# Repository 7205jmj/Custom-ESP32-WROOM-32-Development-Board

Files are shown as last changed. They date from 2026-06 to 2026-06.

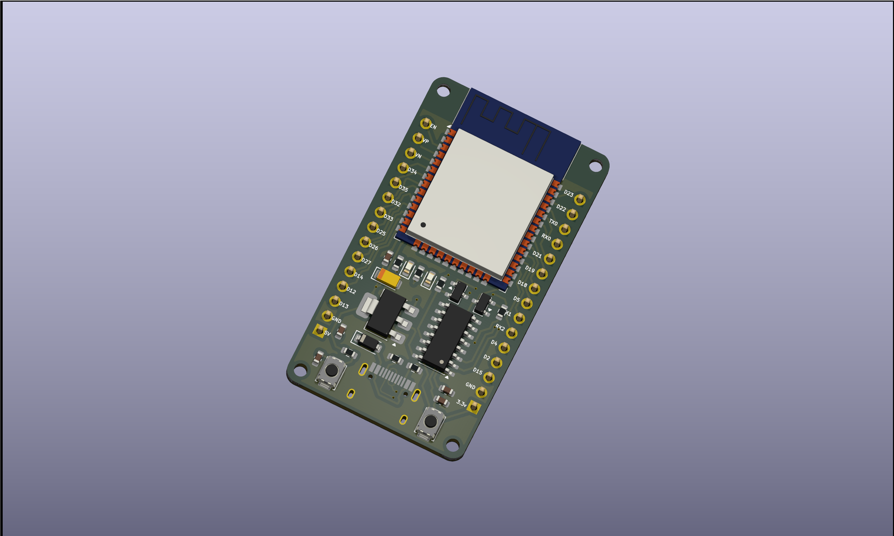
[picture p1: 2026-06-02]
3d_model.png

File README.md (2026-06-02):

# Custom-ESP32-WROOM-32-Development-Board
A professionally designed ESP32-WROOM-32 Development Board created in KiCad for IoT, Embedded Systems, and Rapid Prototyping applications. This project aims to provide a compact, reliable, and cost-effective alternative to commercial ESP32 development boards while exposing essential GPIOs and integrating the required support circuitry for seamless programming and deployment.

Overview

Most ESP32 development boards available in the market include additional features that may not be required for every project. This custom board was designed to provide a clean and optimized ESP32 platform suitable for learning, prototyping, and product development.

The board integrates:

1.ESP32-WROOM-32 module
2.USB-powered operation
3.On-board 3.3V regulation
4.Auto-programming circuit
5.Reset and Boot buttons
6.Status indication LEDs
7.GPIO breakout headers
8.Compact 2-layer PCB layout

Hardware Specifications
Parameter	Specification
Module--->	ESP32-WROOM-32
CPU	---->Dual-Core Xtensa LX6
Clock Frequency------->	Up to 240 MHz
Flash Memory--------->	As per module variant
Operating Voltage	--->3.3V
Input Voltage---->	5V USB
Wireless-------->	Wi-Fi + Bluetooth
PCB Layers---------->	2
Design Software	--------->KiCad

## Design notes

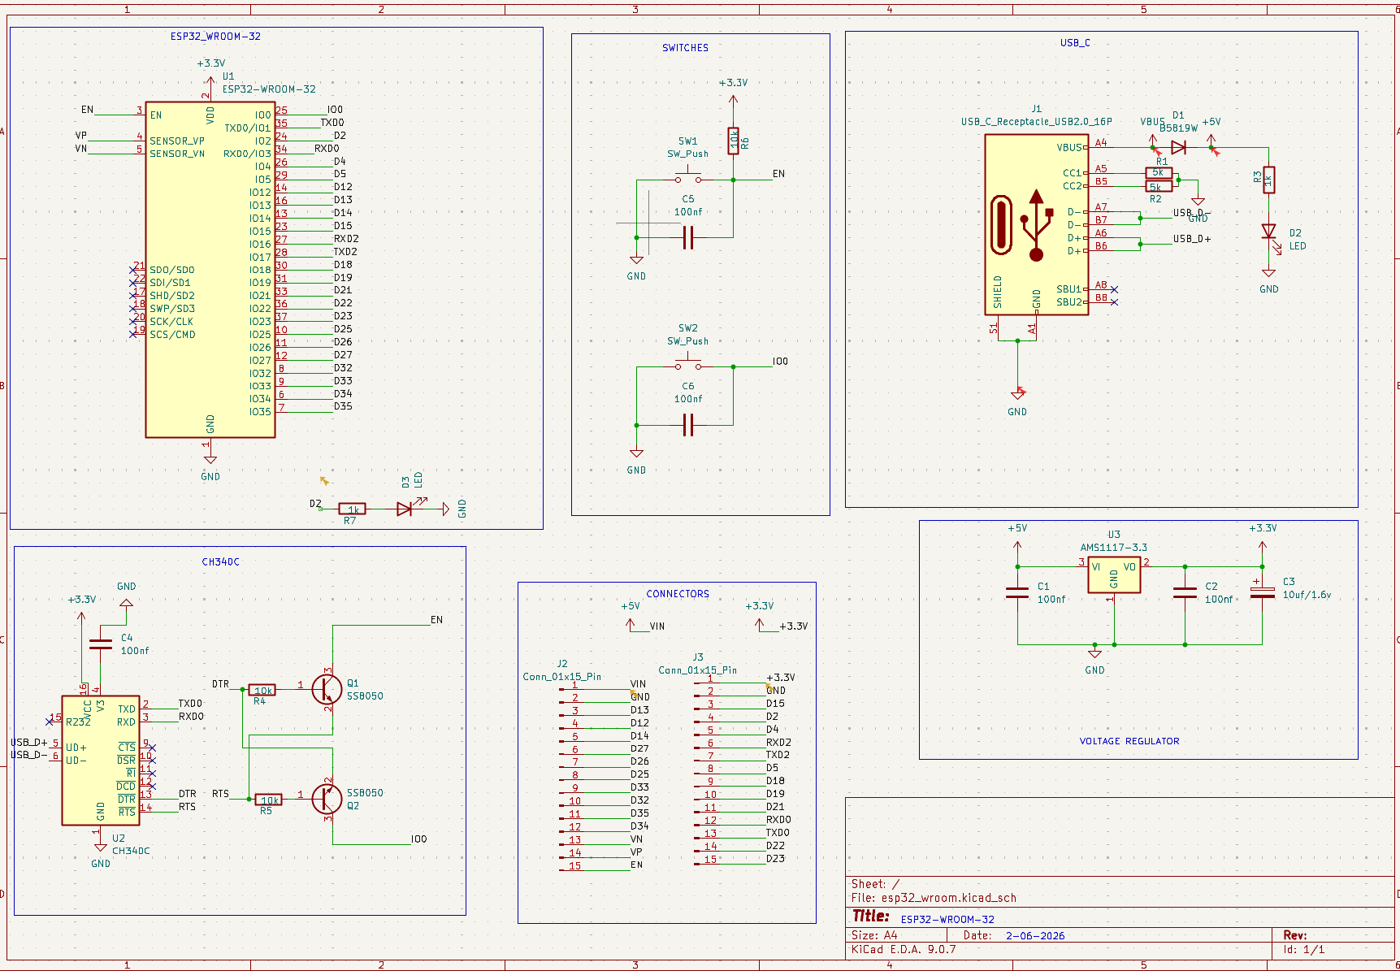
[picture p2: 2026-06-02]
schematic.png

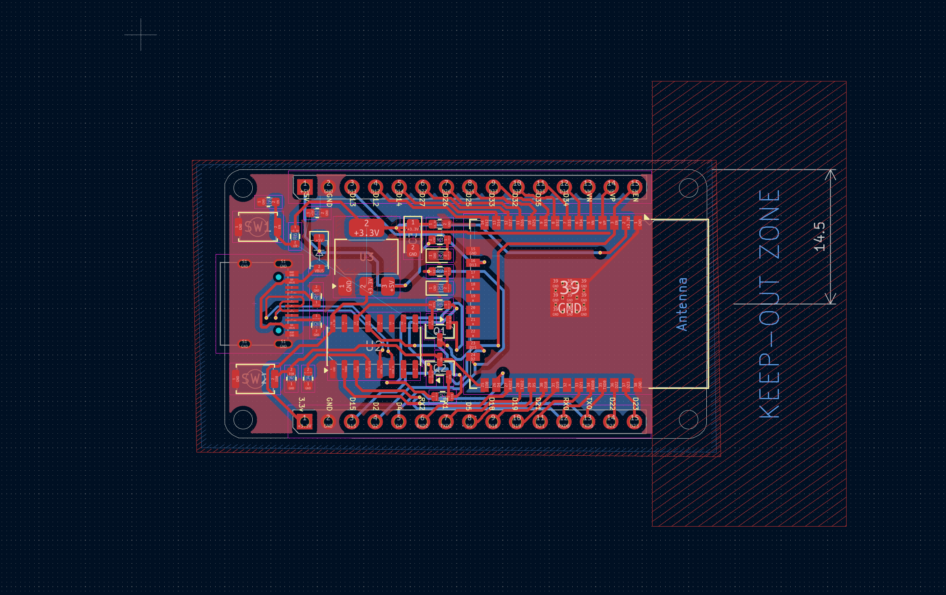
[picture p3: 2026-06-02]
layout.png

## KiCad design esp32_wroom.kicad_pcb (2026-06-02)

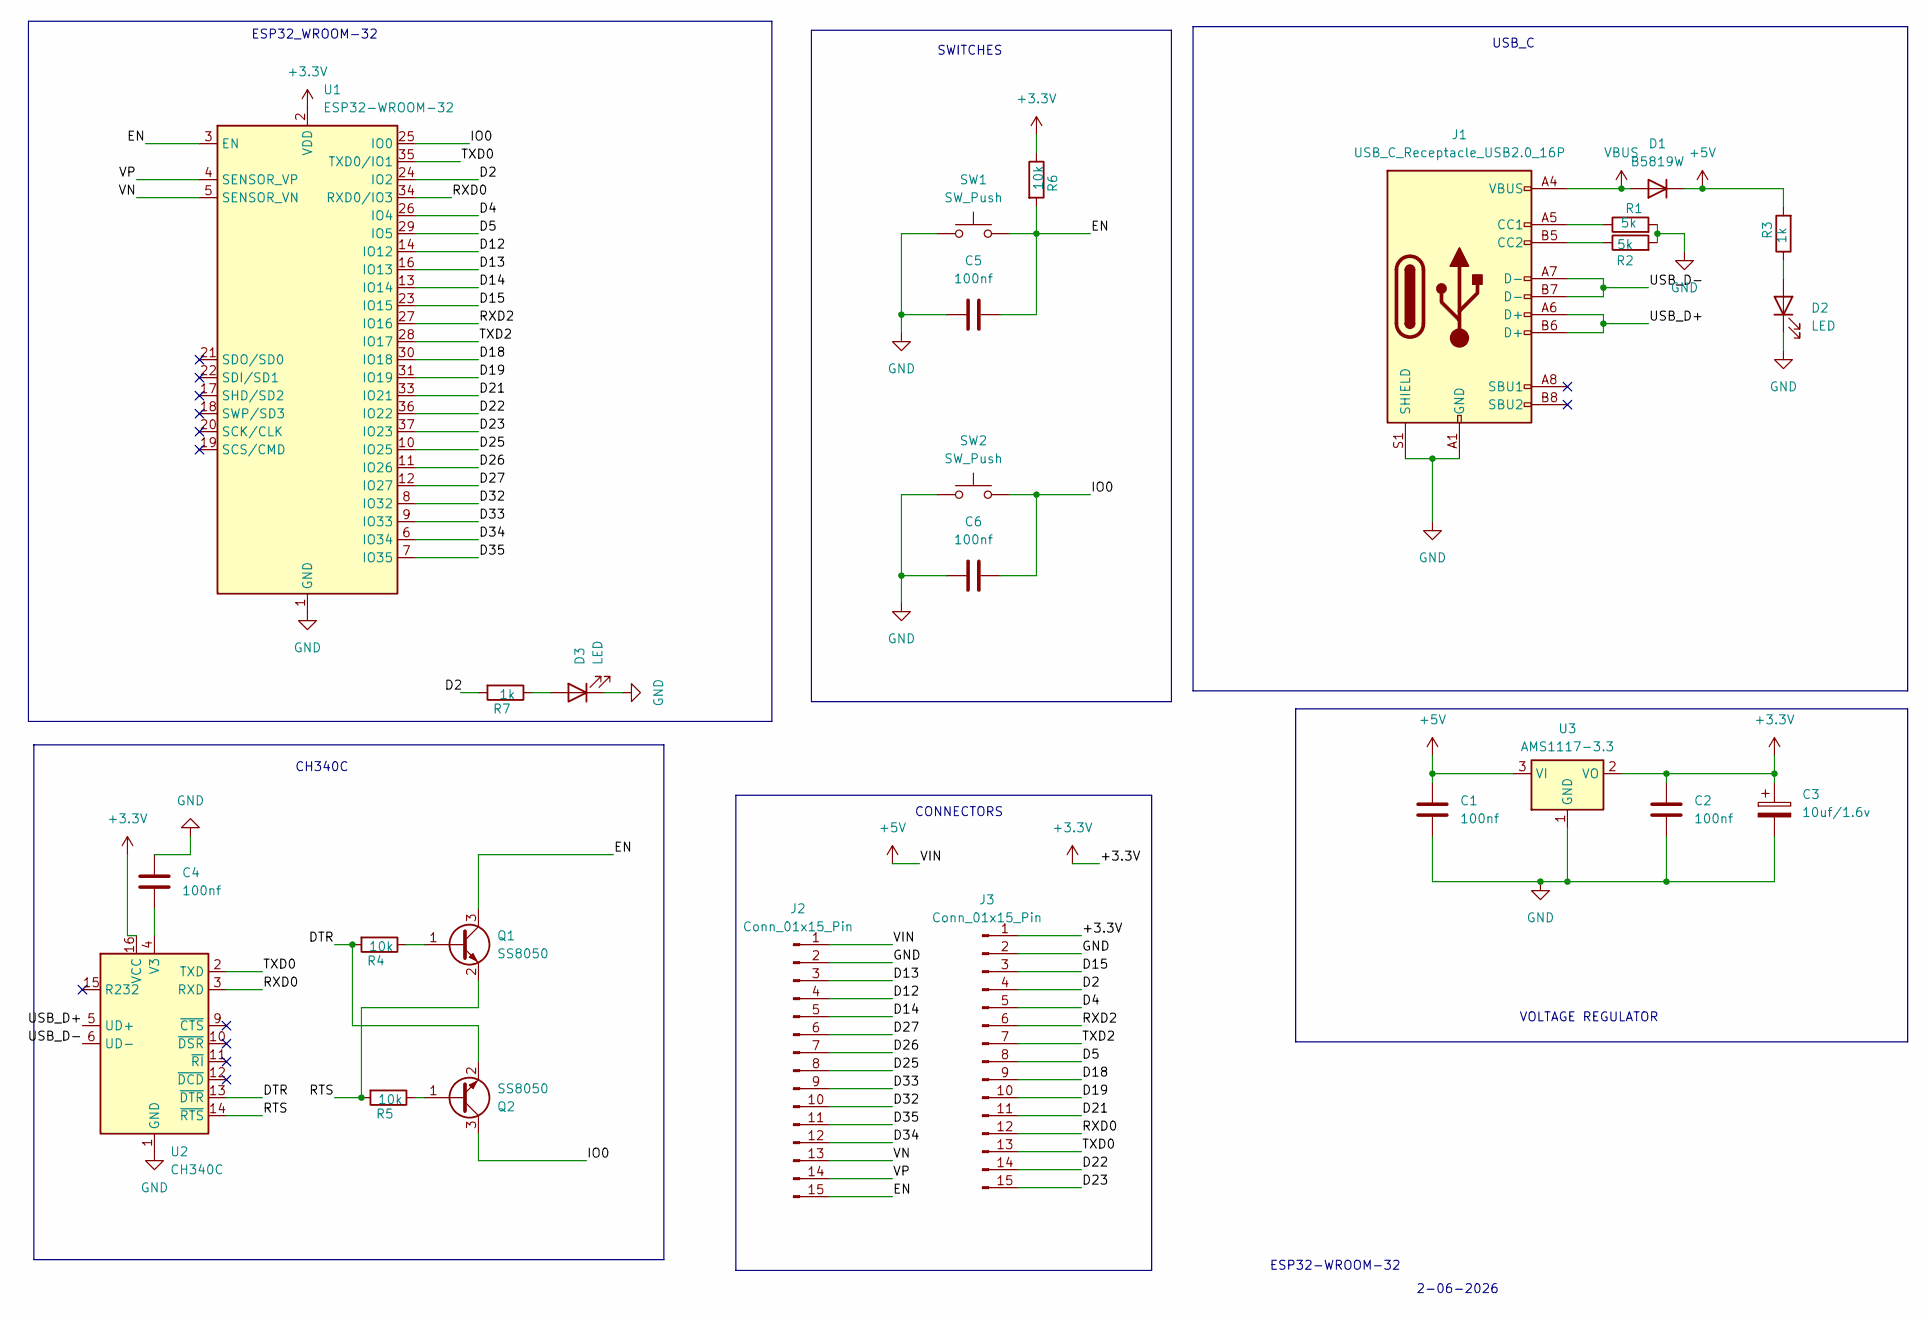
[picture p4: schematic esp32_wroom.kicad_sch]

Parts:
C1, C2, C4, C5, C6: 100nf; C_0603_1608Metric
C3: 10uf/1.6v; CP_EIA-3216-10_Kemet-I
D1: B5819W; D_SOD-123
D2, D3: LED; LED_0603_1608Metric
J1: USB_C_Receptacle_USB2.0_16P; USB_C_Receptacle_HRO_TYPE-C-31-M-12
J2, J3: Conn_01x15_Pin; PinHeader_1x15_P2.54mm_Vertical
Q1, Q2: SS8050; SOT-23
R1, R2: 5k; R_0603_1608Metric
R3, R7: 1k; R_0603_1608Metric
R4, R5, R6: 10k; R_0603_1608Metric
SW1, SW2: SW_Push; SW_Push_SPST_NO_Alps_SKRK
U1: ESP32-WROOM-32
U2: CH340C; SOIC-16_3.9x9.9mm_P1.27mm
U3: AMS1117-3.3; SOT-223-3_TabPin2

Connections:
+3.3V: C2.1, C3.1, J3.1, R6.1, U1.2 (VDD), U2.16 (VCC), U3.2 (VO)
+5V: C1.1, D1.1 (K), J2.1, R3.2, U3.3 (VI)
/D2: J3.4, R7.2, U1.24 (IO2)
/D4: J3.5, U1.26 (IO4)
/D5: J3.8, U1.29 (IO5)
/D12: J2.4, U1.14 (IO12)
/D13: J2.3, U1.16 (IO13)
/D14: J2.5, U1.13 (IO14)
/D15: J3.3, U1.23 (IO15)
/D18: J3.9, U1.30 (IO18)
/D19: J3.10, U1.31 (IO19)
/D21: J3.11, U1.33 (IO21)
/D22: J3.14, U1.36 (IO22)
/D23: J3.15, U1.37 (IO23)
/D25: J2.8, U1.10 (IO25)
/D26: J2.7, U1.11 (IO26)
/D27: J2.6, U1.12 (IO27)
/D32: J2.10, U1.8 (IO32)
/D33: J2.9, U1.9 (IO33)
/D34: J2.12, U1.6 (IO34)
/D35: J2.11, U1.7 (IO35)
/DTR: Q2.2 (E), R4.2, U2.13 (~DTR)
/EN: C5.2, J2.15, Q1.3 (C), R6.2, SW1.2, U1.3 (EN)
/IO0: C6.2, Q2.3 (C), SW2.2, U1.25 (IO0)
/RTS: Q1.2 (E), R5.2, U2.14 (~RTS)
/RXD0: J3.12, U1.34 (RXD0/IO3), U2.3 (RXD)
/RXD2: J3.6, U1.27 (IO16)
/TXD0: J3.13, U1.35 (TXD0/IO1), U2.2 (TXD)
/TXD2: J3.7, U1.28 (IO17)
/USB_D+: J1.A6 (D+), J1.B6 (D+), U2.5 (UD+)
/USB_D-: J1.A7 (D-), J1.B7 (D-), U2.6 (UD-)
/VN: J2.13, U1.5 (SENSOR_VN)
/VP: J2.14, U1.4 (SENSOR_VP)
GND: C1.2, C2.2, C3.2, C4.1, C5.1, C6.1, D2.1 (K), D3.1 (K), J1.A1 (GND), J1.A12 (GND), J1.B1 (GND), J1.B12 (GND), J1.S1 (SHIELD), J2.2, J3.2, R1.2, R2.2, SW1.1, SW2.1, U1.1 (GND), U1.15 (GND), U1.38 (GND), U1.39 (GND), U2.1 (GND), U3.1 (GND)
unnamed: D2.2 (A), R3.1
unnamed: D3.2 (A), R7.1
unnamed: J1.A5 (CC1), R1.1
unnamed: J1.B5 (CC2), R2.1
unnamed: Q1.1 (B), R4.1
unnamed: Q2.1 (B), R5.1
unnamed: C4.2, U2.4 (V3)
VBUS: D1.2 (A), J1.A4 (VBUS), J1.A9 (VBUS), J1.B4 (VBUS), J1.B9 (VBUS)

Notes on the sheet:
SWITCHES
ESP32_WROOM-32
ESP32-WROOM-32
CONNECTORS
CH340C
USB_C
2-06-2026
VOLTAGE REGULATOR

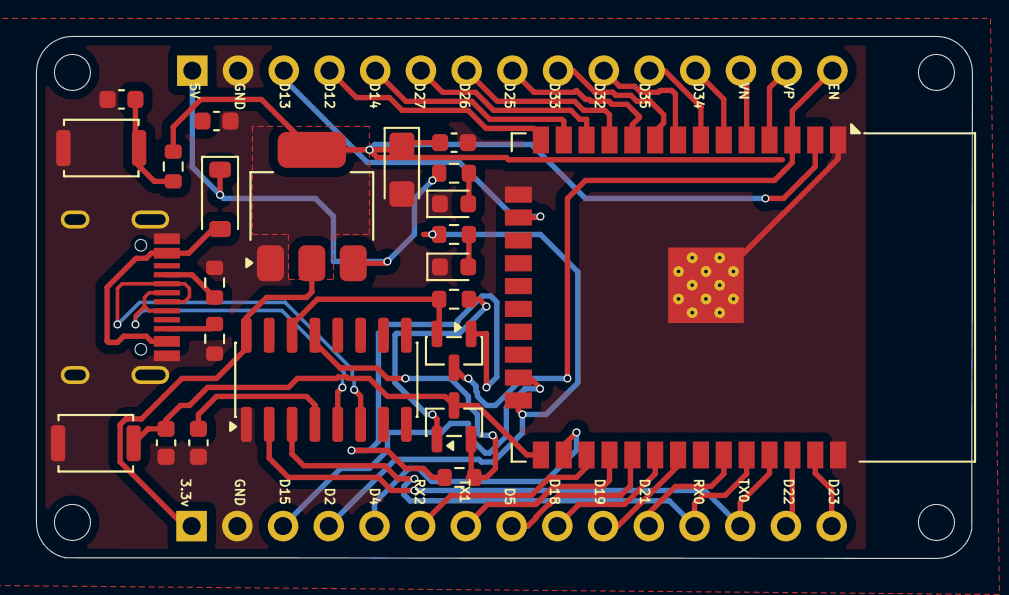
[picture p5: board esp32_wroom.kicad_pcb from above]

Board: 2 copper layers, 52.0 x 29.0 mm, 26 parts (0 on the bottom side), 42 nets.
